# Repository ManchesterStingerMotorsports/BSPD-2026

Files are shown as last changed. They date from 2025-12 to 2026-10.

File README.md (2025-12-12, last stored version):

# BSPD Routing Challenge - Manchester Stinger Motorsports

Welcome to the **BSPD Routing Challenge** for the Manchester Stinger Motorsports Formula Student team.

The aim of this challenge is to compare PCB layout and routing quality across the team using **the same fixed schematic and board constraints**.

You will fork this repository, route the PCB, and submit your solution via GitHub.

---

## Objective

Produce the **best-routed PCB** possible while strictly adhering to the constraints below.

This is a **layout-only challenge** - no schematic edits, no mechanical changes, no shortcuts.

---

## Deadline

**9th of February (23:59)**

---

## How to Enter

1. **Fork this repository**
2. Open the project in **KiCad** 
3. Route the PCB according to the rules below
4. Commit your changes
5. Submit your fork for review

---

## Rules (Read Carefully)

### 1. Schematic - DO NOT CHANGE
- The **schematic must remain completely unchanged**
- No component changes
- No footprint changes
- No net changes

Any schematic modification will result in **disqualification**.

---

### 2. Board Outline & Connectors - FIXED
- **Board dimensions must remain unchanged**
- **Board outline must not be edited**
- **All connectors must stay in their original positions and orientations**
- Do not move connectors even slightly

This ensures all layouts are directly comparable.

---

### 3. What You ARE Allowed to Change
- Component placement (except connectors)
- Track routing
- Via count and placement
- Copper pours / zones
- Layer usage
- Trace widths (within design rules)
- Decoupling capacitor placement (if already present in the schematic)

---

### 4. What You Are NOT Allowed to Do
- Modify the schematic in any way
- Add or remove components
- Change connector positions
- Change board size or shape
- Change footprints

---

## Judging Criteria

Layouts will be judged on:

- Signal integrity
- Routing quality
- Layer usage efficiency
- EMI considerations
- Manufacturability/Solderability
- Overall cleanliness and readability

Bonus points for:
- Thoughtful via usage
- Clear functional grouping
- Good silkscreen labelling (feel free to add cool graphics!!)

---

## Submission Guidelines

- Commit **only PCB layout changes**
- Final submission must build cleanly with **no DRC errors**
- Do not squash or rewrite history after submission
- When you are happy with your submission send me (Jame) a message.

---

## Point of Contact

The point of contact for this challenge is **me** (James Platt).

That said, please **ask questions and discuss openly in the `#st-electronics` Slack channel** wherever possible so everyone benefits.

---

## Notes

This challenge is intended to:
- Improve PCB routing skills across the team
- Encourage discussion around best practice
- Foster healthy competition within the sparky subteams

Best of luck!!

Jame ⚡

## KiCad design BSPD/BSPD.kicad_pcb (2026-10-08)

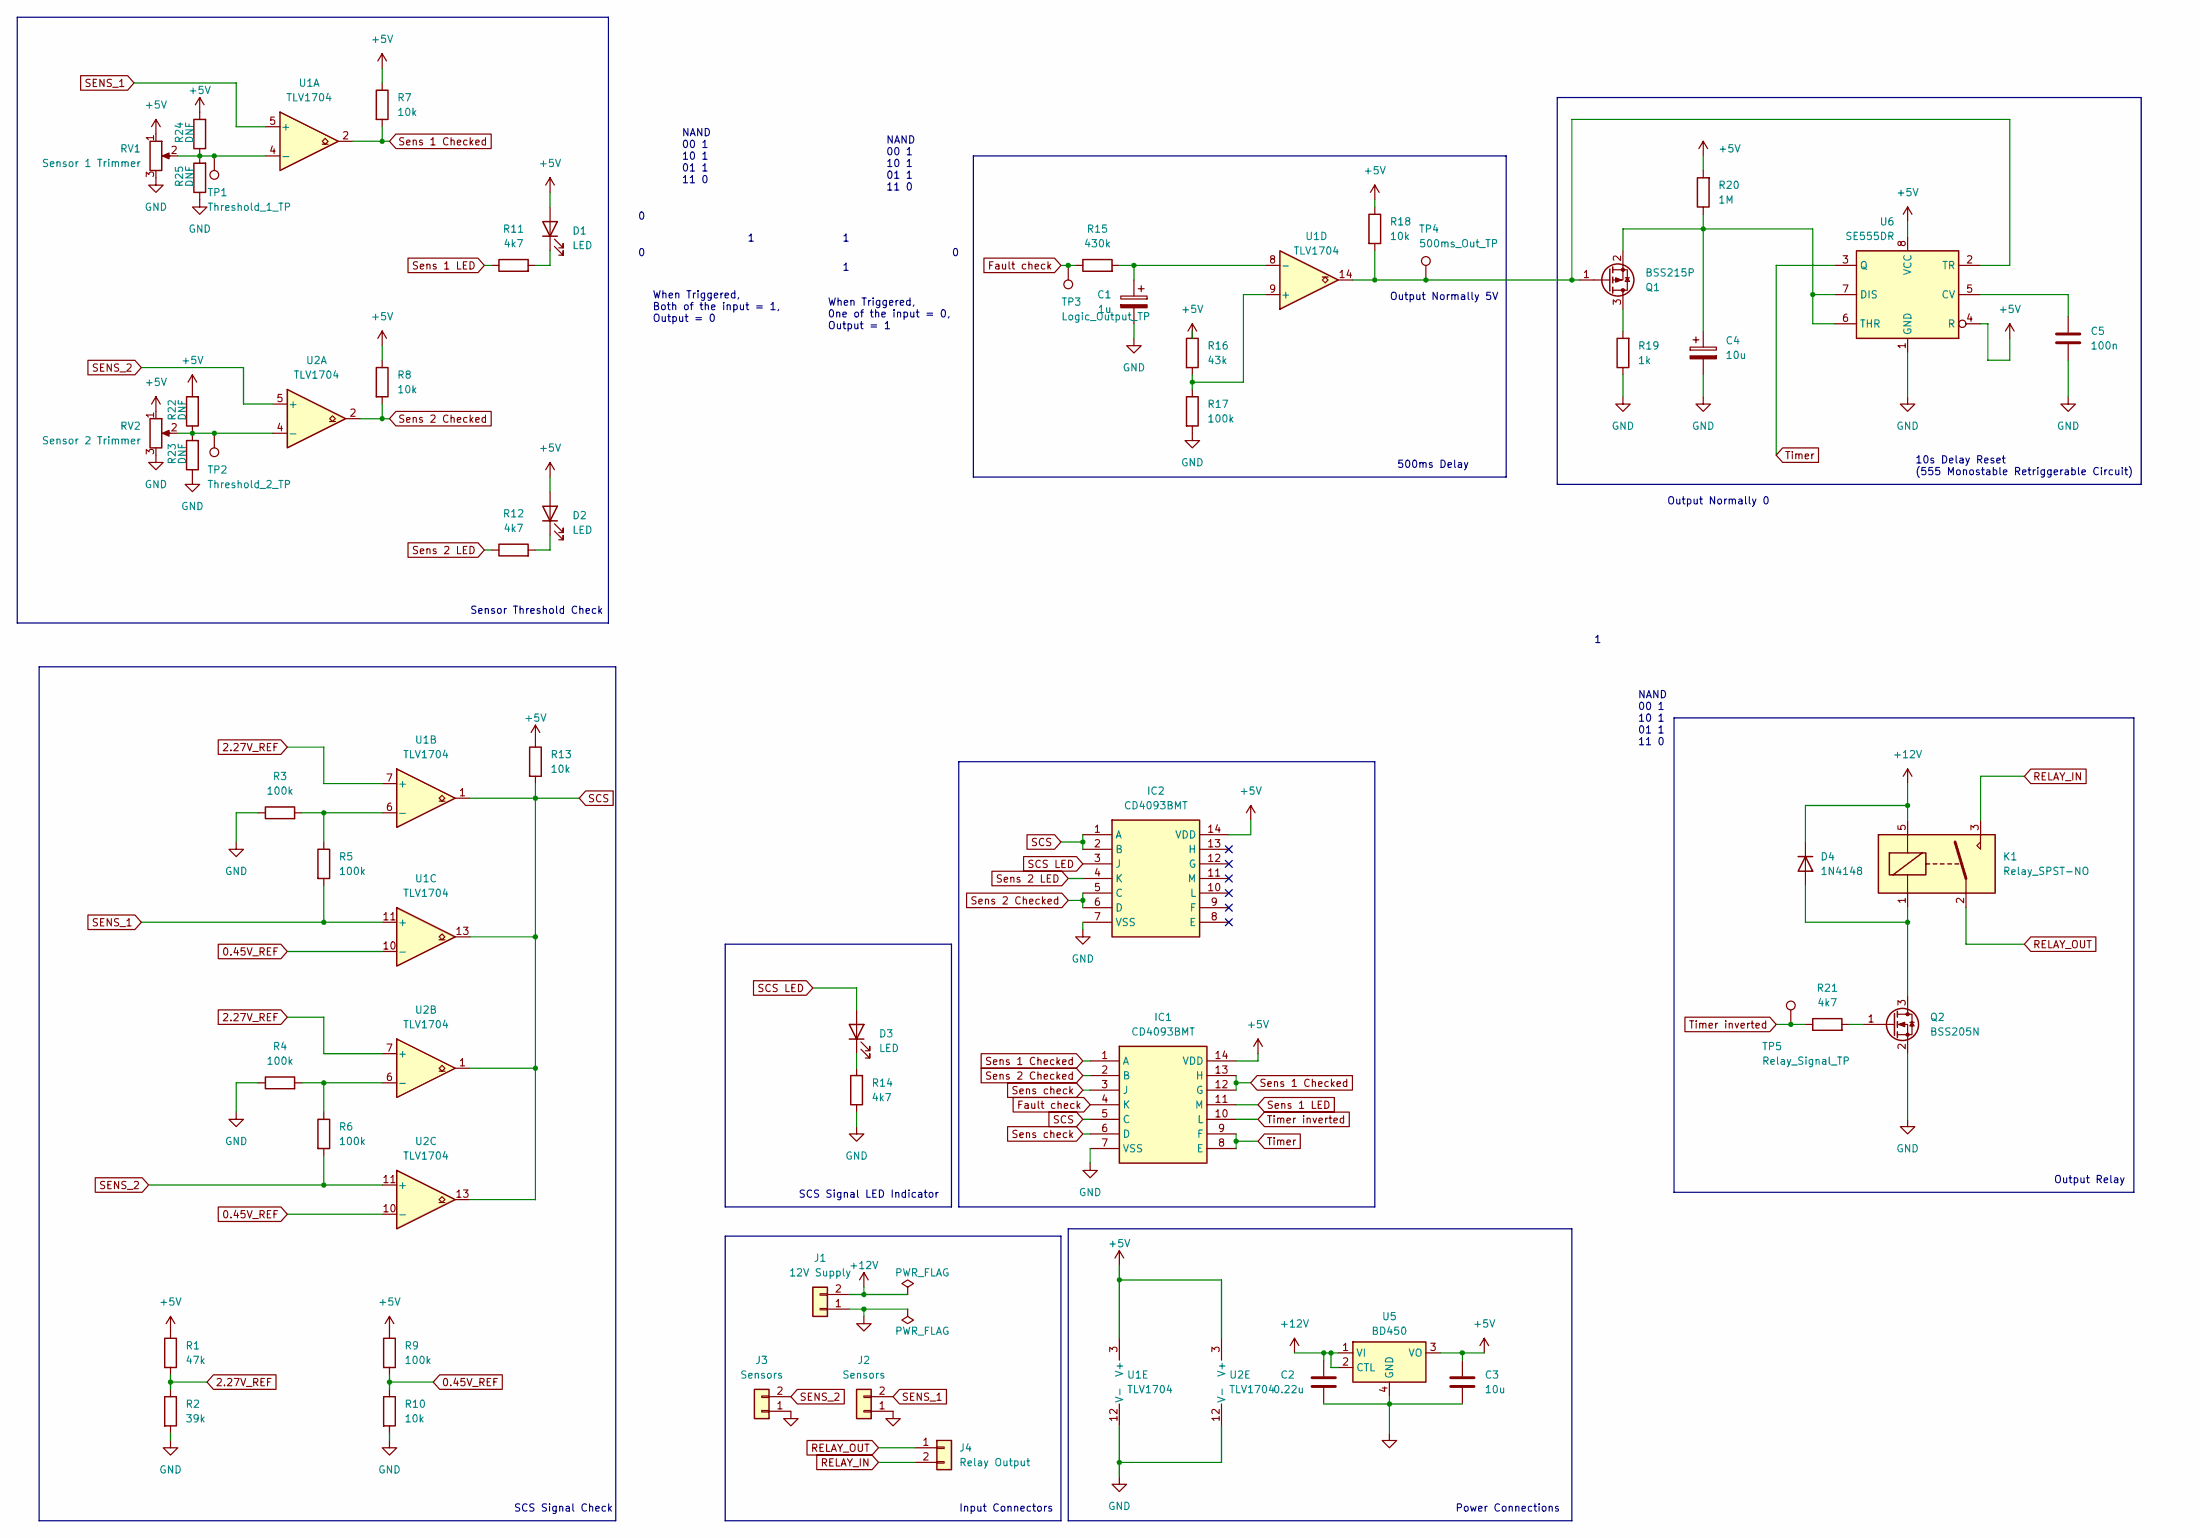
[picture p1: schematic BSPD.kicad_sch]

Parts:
C1: 1u; C_0603_1608Metric
C2: 0.22u; C_0603_1608Metric
C3, C4: 10u; C_0603_1608Metric
C5: 100n; C_0603_1608Metric
D1, D2, D3: LED; LED_0603_1608Metric
D4: 1N4148; SOD-123_VISHAY
IC1, IC2: CD4093BMT; Cd4093b; Manufacturer_Part_Number CD4093BMT; Mouser Part Number 595-CD4093BMT
J1: 12V Supply; JST_XA_S02B-XASK-1_1x02_P2.50mm_Horizontal
J2, J3: Sensors; JST_XA_S02B-XASK-1_1x02_P2.50mm_Horizontal
J4: Relay Output; JST_XA_S02B-XASK-1_1x02_P2.50mm_Horizontal
K1: Relay_SPST-NO; RELAY_G6RN-1_OMR
Q1: BSS215P; MOSFET_Single_SOT-23
Q2: BSS205N; MOSFET_Single_SOT-23
R1: 47k; R_0603_1608Metric
R2: 39k; R_0603_1608Metric
R3, R4, R5, R6, R9, R17: 100k; R_0603_1608Metric
R7, R8, R10, R13, R18: 10k; R_0603_1608Metric
R11, R12, R14, R21: 4k7; R_0603_1608Metric
R15: 430k; R_0603_1608Metric
R16: 43k; R_0603_1608Metric
R19: 1k; R_0603_1608Metric
R20: 1M; R_0603_1608Metric
R22, R23, R24, R25: DNF; R_0603_1608Metric
RV1: Sensor 1 Trimmer; Bourns_3314G-1
RV2: Sensor 2 Trimmer; Bourns_3314G-1
TP1: Threshold_1_TP; TestPoint_Pad_2.0x2.0mm
TP2: Threshold_2_TP; TestPoint_Pad_2.0x2.0mm
TP3: Logic_Output_TP; TestPoint_Pad_2.0x2.0mm
TP4: 500ms_Out_TP; TestPoint_Pad_2.0x2.0mm
TP5: Relay_Signal_TP; TestPoint_Pad_2.0x2.0mm
U1, U2: TLV1704; PW14_TEX
U5: BD450; Regulator_Linear_SOT-223-4
U6: SE555DR; D8

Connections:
0.45V_REF: R9.2, R10.1, U1.10 (-), U2.10 (-)
2.27V_REF: R1.2, R2.1, U1.7 (+), U2.7 (+)
+5V: C3.1, D1.2 (A), D2.2 (A), IC1.14 (VDD), IC2.14 (VDD), R1.1, R7.1, R8.1, R9.1, R13.1, R16.1, R18.1, R20.2, R22.2, R24.2, RV1.1, RV2.1, U1.3 (V+), U2.3 (V+), U5.3 (VO), U6.4 (R), U6.8 (VCC)
+12V: C2.1, D4.1 (K), J1.2, K1.5, U5.1 (VI), U5.2 (CTL)
Fault check: IC1.4 (K), R15.1, TP3.1 (1_1)
GND: C1.2, C2.2, C3.2, C4.2, C5.2, IC1.7 (VSS), IC2.7 (VSS), J1.1, J2.1, J3.1, Q2.2 (S), R2.2, R3.1, R4.1, R10.2, R14.1, R17.2, R19.1, R23.1, R25.1, RV1.3, RV2.3, U1.12 (V-), U2.12 (V-), U5.4 (GND), U6.1 (GND)
unnamed: D1.1 (K), R11.2
unnamed: D2.1 (K), R12.2
unnamed: D3.1 (K), R14.2
unnamed: D4.2 (A), K1.1, Q2.3 (D)
unnamed: Q1.3 (D), R19.2
unnamed: Q1.1 (G), R18.2, TP4.1 (1_1), U1.14, U6.2 (TR)
unnamed: C4.1, Q1.2 (S), R20.1, U6.6 (THR), U6.7 (DIS)
unnamed: Q2.1 (G), R21.2
unnamed: R24.1, R25.2, RV1.2, TP1.1 (1_1), U1.4 (-)
unnamed: R3.2, R5.1, U1.6 (-)
unnamed: R16.2, R17.1, U1.9 (+)
unnamed: C1.1, R15.2, U1.8 (-)
unnamed: R22.1, R23.2, RV2.2, TP2.1 (1_1), U2.4 (-)
unnamed: R4.2, R6.1, U2.6 (-)
unnamed: C5.1, U6.5 (CV)
RELAY_IN: J4.2, K1.3
RELAY_OUT: J4.1, K1.2
SCS: IC1.5 (C), IC2.1 (A), IC2.2 (B), R13.2, U1.1, U1.13, U2.1, U2.13
SCS LED: D3.2 (A), IC2.3 (J)
SENS_1: J2.2, R5.2, U1.5 (+), U1.11 (+)
SENS_2: J3.2, R6.2, U2.5 (+), U2.11 (+)
Sens 1 Checked: IC1.1 (A), IC1.12 (G), IC1.13 (H), R7.2, U1.2
Sens 1 LED: IC1.11 (M), R11.1
Sens 2 Checked: IC1.2 (B), IC2.5 (C), IC2.6 (D), R8.2, U2.2
Sens 2 LED: IC2.4 (K), R12.1
Sens check: IC1.3 (J), IC1.6 (D)
Timer: IC1.8 (E), IC1.9 (F), U6.3 (Q)
Timer inverted: IC1.10 (L), R21.1, TP5.1 (1_1)

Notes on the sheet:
SCS Signal Check
When Triggered, Both of the input = 1, Output = 0
500ms Delay
Output Relay
SCS Signal LED Indicator
Power Connections
NAND 00 1 10 1 01 1 11 0
Sensor Threshold Check
Output Normally 5V
Input Connectors
When Triggered, 0ne of the input = 0, Output = 1
10s Delay Reset (555 Monostable Retriggerable Circuit)
Output Normally 0

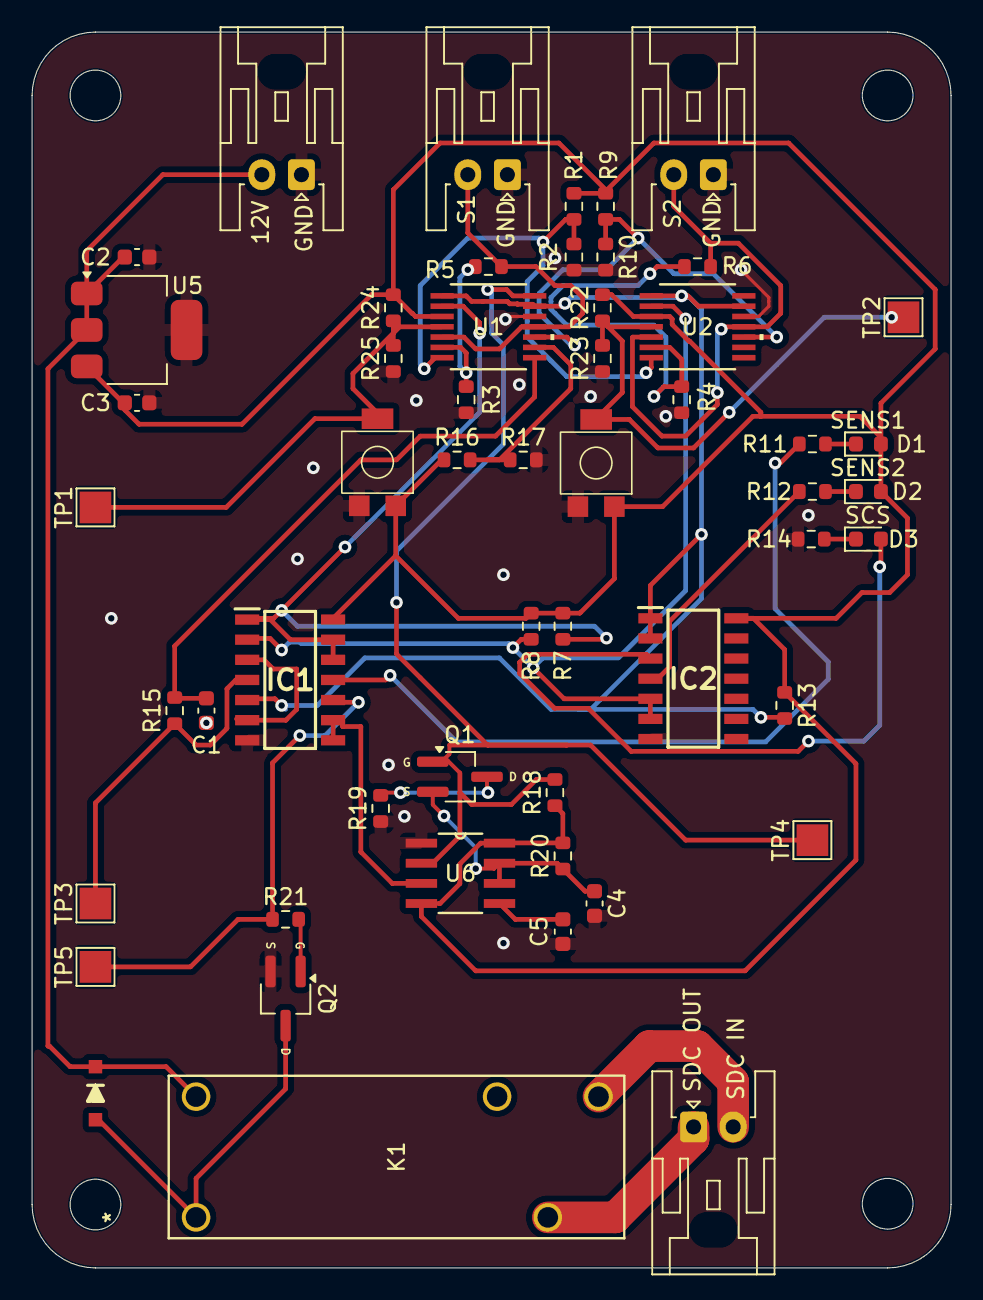
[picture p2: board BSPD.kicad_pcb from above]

Board: 2 copper layers, 58.0 x 78.0 mm, 54 parts (0 on the bottom side), 34 nets.

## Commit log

2026-02-10 Current Schem and defined board layout
    [BSPD_ManchesterStingerMotorsports.kicad_pcb, BSPD_ManchesterStingerMotorsports.kicad_sch]
2026-02-10 Update
    Changed outdated footprints to standard ones
    [BSPD_ManchesterStingerMotorsports.kicad_pcb, BSPD_ManchesterStingerMotorsports.kicad_sch]
2026-02-10 Finalised Schematic
    [BSPD 1002.kicad_pcb, BSPD 1002.kicad_sch]
2026-02-11 "Ready to buy"
    [BSPD 1002.kicad_pcb]
2026-05-07 Fixed The footprint and used different symbols
    [BSPD 1003.kicad_pcb, BSPD 1003.kicad_sch]
2026-05-12 Fixed diode footprint
    [BSPD 1003.kicad_pcb, BSPD 1003.kicad_sch]
2026-05-14 clean up
    [BSPD 1003.kicad_pcb, BSPD 1003.kicad_sch, BSPD.kicad_pcb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]
2026-06-09 ready to go
    [BSPD.kicad_pcb, BSPD.kicad_sch]
2026-10-08 Changed 555 Timer's N-Mosfet to P-mosfet
    [BSPD.kicad_pcb, BSPD.kicad_sch]
2026-11-02 Fixed the ground pour shape
2026-11-05 Swapped out EMI relay for SSR
